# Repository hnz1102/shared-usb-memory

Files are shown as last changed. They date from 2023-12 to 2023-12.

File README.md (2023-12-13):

<div align="center">
  <h1><code>SHARED-USB-MEMORY</code></h1>
  <p>
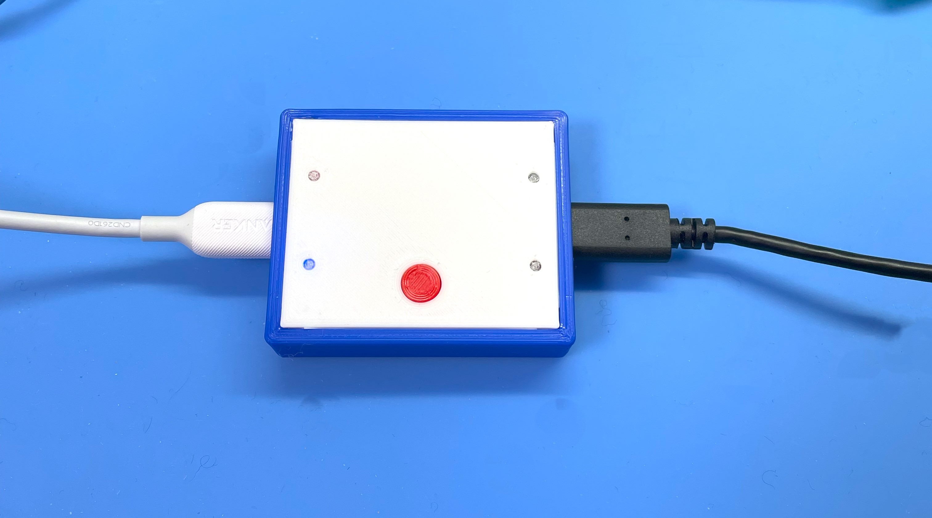
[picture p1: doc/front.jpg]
    
  </p>
</div>

# Shared USB Memory : USB Memory with One-touch Switching Between Two Device Connections

https://github.com/hnz1102/shared-usb-memory/assets/111413646/2c444520-a98f-45e1-a0ac-f0b2667a8621

This memory provides convenient and quick-to-switch connections between two host devices such as PCs.

When the network is not available, data is transferred by copying data to and from a USB memory stick or SD card. However, since removing and inserting USB memory sticks and SD cards is a hassle, the Box can be switched at the touch of a button to pass data back and forth.

To use, connect this Box between two PCs with a Type-C cable. The disk will be recognized by the PC connected to the left port. Then, copy data here, and when the red access blinking stops, press the red button. Then the disk will be recognized in the PC of right port and you can retrieve the data. Press the red button again to return the disk to the left PC. In this way, data can be exchanged without having to remove and insert the USB memory stick.

The box can be run on the Windows OS, MacOS, and Linux OS without special drivers.

## Schematic

This Board Schematic and a PCB layout are placed in this directory. 
Schematic data is created by KidCad 7.0.
The PCB was manufuctured by [PCBWay](https://www.pcbway.com/). I could easily order my custom boards to the PCBWay.
Click online order [page](https://www.pcbway.com/QuickOrderOnline.aspx), then clink the "Add Gerber File" button, you can upload the [gerber file](https://github.com/hnz1102/shared-usb-memory/raw/main/shareusbdisk2.kicad_pcb.zip).

When ordering the PCB, the parameters can be almost default values, but "Min hole size" should be 0.25mm and "Immersion gold (ENIG)" should be selected for "Surface finish". The reason for this is that the minimum Via Hole is 0.25mm, and if the eMMC pad is not "Immersion gold (ENIG)", the solder on the pad will be slightly raised and cannot be soldered properly without misalignment.

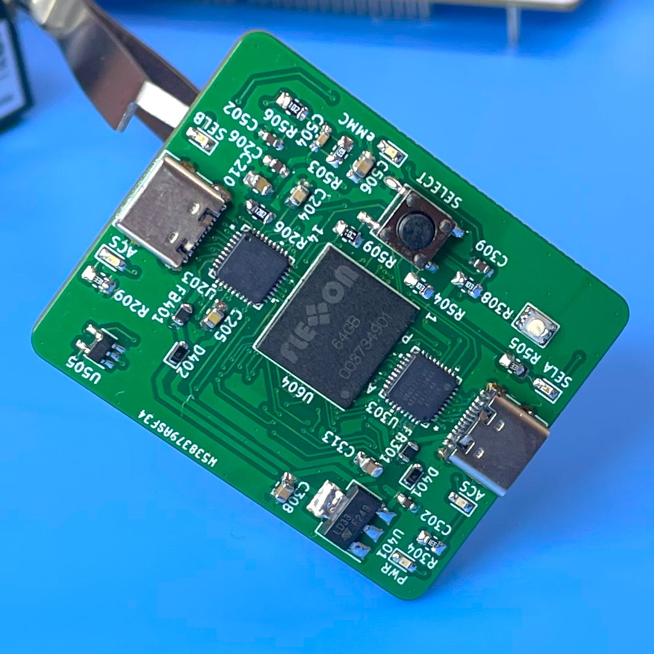
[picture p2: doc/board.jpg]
PCB


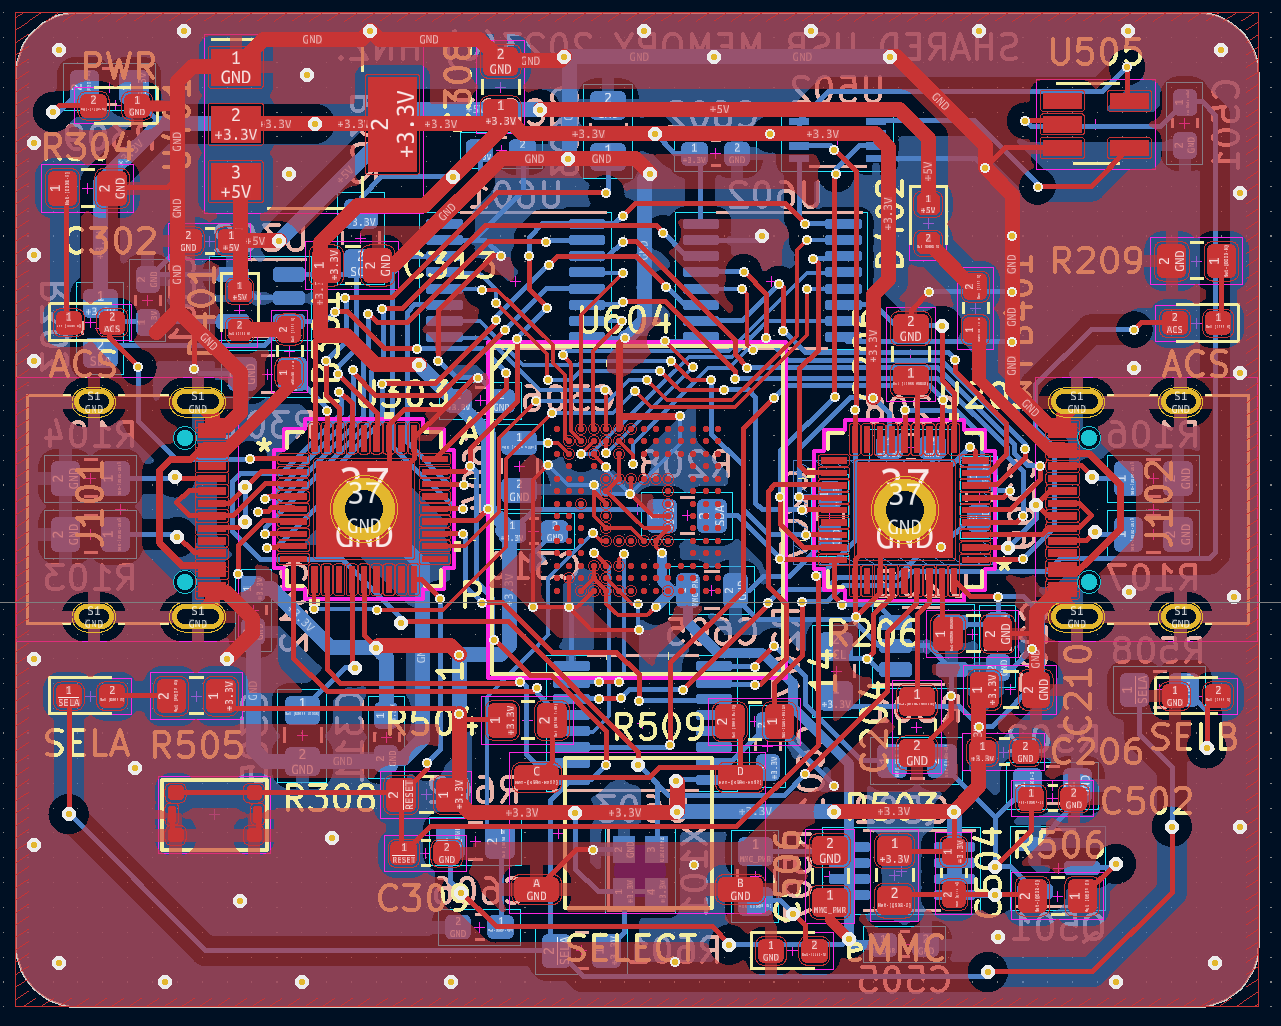
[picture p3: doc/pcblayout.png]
PCB Layout


After assembling the board, It has to configure EEPROMs of the USB Media Controller.

The USB Media Controller has an EEPROM. It is programmed with the parameters by [USBDM tool](https://www.microchip.com/en-us/software-library/usbdm-tool).

- Manufacture String
- Serial Number String

This board has two USB Media Controller. Connect to each of the two respective USB ports and rewrite the information with the USBDM tool. 

# Container

There are STL data for 3D printer in the `stl` directory.

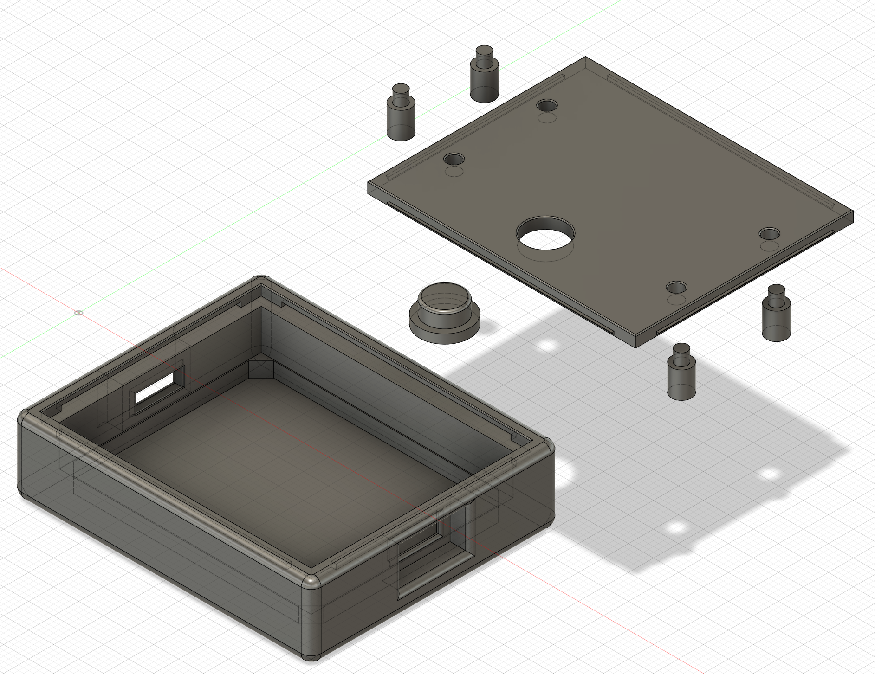
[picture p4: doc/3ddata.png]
container


## LICENSE
Hardware Schematic Documents are licensed under CC-BY-SA V4.0.

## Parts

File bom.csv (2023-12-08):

Reference | Value | Footprint | Datasheet | digikey | storeURL | Qty
C206-C209, C301, C302, C306, C309-C312, C501, C502, C505, C601-C603, C606 | 0.1uF | Capacitor_SMD:C_0603_1608Metric_Pad1.08x0.95mm_HandSolder | ~ | 311-1824-1-ND | https://www.digikey.com/en/products/detail/yageo/CC0603MRX7R7BB104/5195231 | 19
C204, C205, C303, C305 | 1uF | tbctl:C_0805_2012Metric_Pad1.18x1.45mm_HandSolder | ~ | 13-CC0603KPX7R7BB105CT-ND | https://www.digikey.com/en/products/detail/yageo/CC0603KPX7R7BB105/11491211 | 4
C210, C313 | 4.7uF | tbctl:C_0805_2012Metric_Pad1.18x1.45mm_HandSolder | ~ | 311-1455-1-ND | https://www.digikey.com/en/products/detail/yageo/CC0603KRX5R6BB475/2833620 | 2
C308, C506 | 10uF | Capacitor_SMD:C_0805_2012Metric_Pad1.18x1.45mm_HandSolder | ~ | 311-3494-1-ND | https://www.digikey.com/en/products/detail/yageo/CC0603MRX5R8BB106/7164378 | 2
C504 | 2.2uF | Capacitor_SMD:C_0603_1608Metric_Pad1.08x0.95mm_HandSolder | ~ | 311-1795-1-ND | https://www.digikey.com/en/products/detail/yageo/CC0603KRX7R5BB225/5195203 | 1
C604, C605 | 1uF | Capacitor_SMD:C_0805_2012Metric | ~ | 13-CC0603KPX7R7BB105CT-ND | https://www.digikey.com/en/products/detail/yageo/CC0603KPX7R7BB105/11491211 | 2
D203, D301, D302 | LED RED | tbctl:LED_0603_1608Metric_Pad1.05x0.95mm_HandSolder | ~ | 511-1587-1-ND | https://www.digikey.com/en/products/detail/rohm-semiconductor/SML-E12V8WT86/1641806 | 3
D401, D402 | CDBU0520-HF | Diode_SMD:D_0603_1608Metric | https://www.comchiptech.com/admin/files/product/QW-G1012-CDBU40-HF-RevA321692.pdf | 641-2022-1-ND | https://www.digikey.com/en/products/detail/comchip-technology/CDBU0520-HF/3308520 | 2
D501 | eMMC PWR LED RED | tbctl:LED_0603_1608Metric_Pad1.05x0.95mm_HandSolder | ~ | 511-1587-1-ND | https://www.digikey.com/en/products/detail/rohm-semiconductor/SML-E12V8WT86/1641806 | 1
D502 | SEL_A | tbctl:LED_0603_1608Metric_Pad1.05x0.95mm_HandSolder | ~ | 846-1177-1-ND | https://www.digikey.com/en/products/detail/rohm-semiconductor/SMLE13BC8TT86/5053771 | 1
D503 | SEL_B | tbctl:LED_0603_1608Metric_Pad1.05x0.95mm_HandSolder | ~ | 846-1177-1-ND | https://www.digikey.com/en/products/detail/rohm-semiconductor/SMLE13BC8TT86/5053771 | 1
FB301, FB401 | BK2125HS601-T | tbctl:L_0603_1608Metric_Pad1.05x0.95mm_HandSolder | ~ | 240-2399-1-ND | https://www.digikey.com/en/products/detail/laird-signal-integrity-products/HZ0805E601R-10/806759 | 2
J101, J102 | USB_C_Receptacle_USB2.0_5077CR | tbctl:USB_C_5077CR-16-SMC2-BK-TR | https://www.usb.org/sites/default/files/documents/usb_type-c.zip | 2073-USB4105-GF-ACT-ND | https://www.digikey.com/en/products/detail/gct/USB4105-GF-A/11198441 | 2
Q501 | 2N7002K | Package_TO_SOT_SMD:SOT-23 | https://www.diodes.com/assets/Datasheets/ds30896.pdf | 2N7002K-7DICT-ND | https://www.digikey.com/en/products/detail/diodes-incorporated/2N7002K-7/1934378 | 1
Q502 | IRF7606TRPBF | Package_SO:MSOP-8_3x3mm_P0.65mm | http://www.irf.com/product-info/datasheets/data/irf7606pbf.pdf | IRF7606TRPBFCT-ND | https://www.digikey.com/en/products/detail/infineon-technologies/IRF7606TRPBF/856652 | 1
R103, R104, R106, R107 | 5.1K | tbctl:R_0805_2012Metric_Pad1.20x1.40mm_HandSolder | ~ | 13-RC0603JR-1010KLCT-ND | https://www.digikey.com/en/products/detail/yageo/RC0603JR-1010KL/13694233 | 4
R206, R301 | 12K 1% | tbctl:R_0805_2012Metric_Pad1.20x1.40mm_HandSolder | ~ | 311-12.0KHRCT-ND | https://www.digikey.com/en/products/detail/yageo/RC0603FR-0712KL/726913 | 2
R207, R208, R302, R303, R308, R502-R504, R601, R602 | 10K | tbctl:R_0805_2012Metric_Pad1.20x1.40mm_HandSolder | ~ | 13-RC0603JR-1010KLCT-ND | https://www.digikey.com/en/products/detail/yageo/RC0603JR-1010KL/13694233 | 10
R209, R304 | 330R | tbctl:R_0805_2012Metric_Pad1.20x1.40mm_HandSolder | ~ | 311-330GRCT-ND | https://www.digikey.com/en/products/detail/yageo/RC0603JR-07330RL/726769 | 2
R309, R506, R507, R509 | 1K | tbctl:R_0805_2012Metric_Pad1.20x1.40mm_HandSolder | ~ | 13-RC0603JR-101KLCT-ND | https://www.digikey.com/en/products/detail/yageo/RC0603JR-101KL/13694236 | 4
R501 | 2K | tbctl:R_0805_2012Metric_Pad1.20x1.40mm_HandSolder | ~ | 311-2.0KGRCT-ND | https://www.digikey.com/en/products/detail/yageo/RC0603JR-072KL/726726 | 1
R505, R508 | 330 | tbctl:R_0805_2012Metric_Pad1.20x1.40mm_HandSolder | ~ | 13-RC0603JR-101KLCT-ND | https://www.digikey.com/en/products/detail/yageo/RC0603JR-101KL/13694236 | 2
SW301 | RESET SW | tbctl:WS-TASV SMT Tact Switch |  | 732-435151014824CT-ND | https://www.digikey.com/en/products/detail/w%C3%BCrth-elektronik/435151014824/11627325 | 1
SW501 | TS-06104 | tbctl:TS-06104 |  |  | https://akizukidenshi.com/catalog/g/gP-15969/ | 1
U202, U302 | AT24C04-STUM | Package_TO_SOT_SMD:SOT-23-5 | http://ww1.microchip.com/downloads/en/DeviceDoc/Atmel-8766-SEEPROM-AT24CS04-08-Datasheet.pdf | AT24C04C-STUM-TCT-ND | https://www.digikey.com/en/products/detail/microchip-technology/AT24C04C-STUM-T/3789511 | 2
U203, U303 | USB2244-AEZG-06 | tbctl:QFN36_6X6MC_MCH | USB2244-AEZG-06 | USB2244-AEZG-06-ND | https://www.digikey.com/en/products/detail/microchip-technology/USB2244-AEZG-06/3873146 | 2
U401 | LD1117S33TR_SOT223 | Package_TO_SOT_SMD:SOT-223-3_TabPin2 | http://www.st.com/st-web-ui/static/active/en/resource/technical/document/datasheet/CD00000544.pdf | 497-1242-1-ND | https://www.digikey.com/en/products/detail/stmicroelectronics/LD1117S33TR/585766 | 1
U502 | 74LVC2G74 | Package_SO:VSSOP-8_2.3x2mm_P0.5mm |  | TC7W74FKLFCT-ND | https://www.digikey.com/en/products/detail/toshiba-semiconductor-and-storage/TC7W74FK-LF/870742 | 1
U505 | 74AHC1G14 | Package_TO_SOT_SMD:SOT-23-5_HandSoldering |  | 74AHC1G14W5-7DICT-ND | https://www.digikey.com/en/products/detail/diodes-incorporated/74AHC1G14W5-7/2639249 | 1
U601-U603 | TMUX1574PWR | Package_SO:TSSOP-16_4.4x5mm_P0.65mm |  | 296-53444-1-ND | https://www.digikey.com/en/products/detail/texas-instruments/TMUX1574PWR/9954224 | 3
U604 | EM32VSUKN | tbctl:EM32VSUKN FPGA153 |  | 3247-EM32VSUKN-BA000-2-ND | https://www.digikey.com/en/products/detail/delkin-devices-inc/EM32VSUKN-BA000-2/16357650 | 1
X101 | SG-210STF 24MHz | Oscillator:Oscillator_SMD_SeikoEpson_SG210-4Pin_2.5x2.0mm | https://support.epson.biz/td/api/doc_check.php?mode=dl&lang=en&Parts=SG-210STF | SER4078CT-ND | https://www.digikey.com/en/products/detail/epson/SG-210STF-24-0000ML0/4437389 | 1

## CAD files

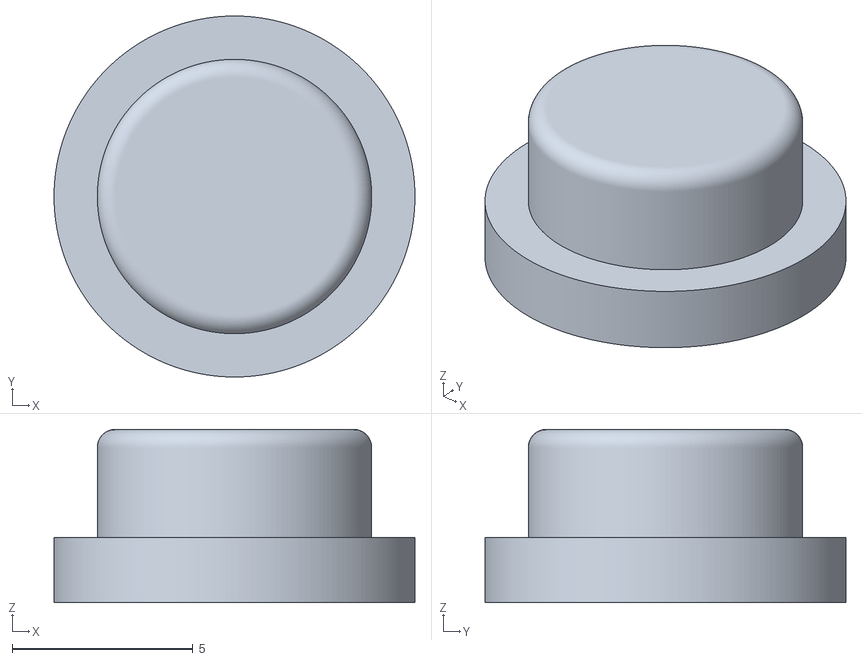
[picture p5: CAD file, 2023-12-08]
stl/button-v6.stl
10.0 x 10.00 x 4.80

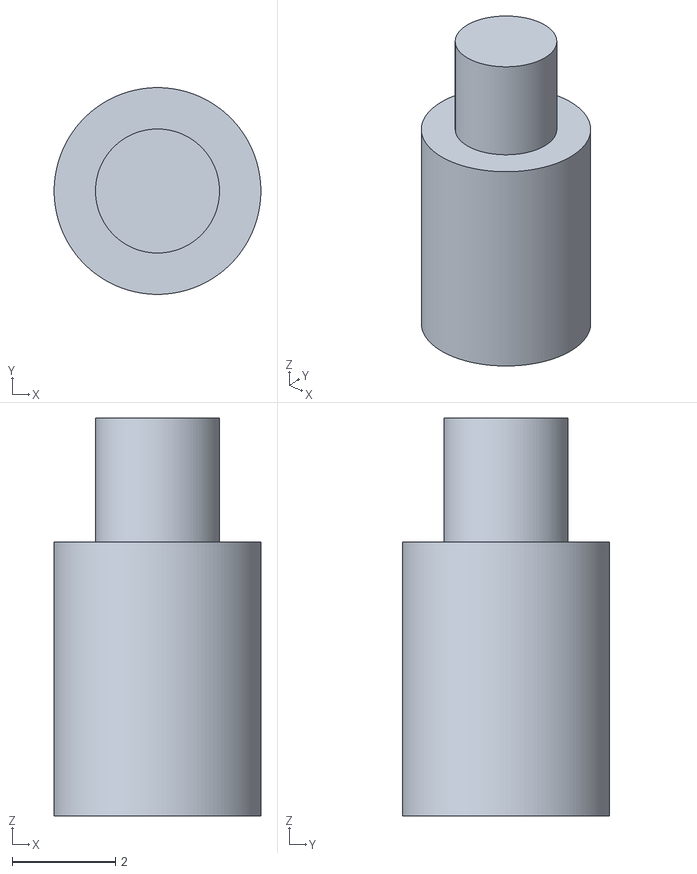
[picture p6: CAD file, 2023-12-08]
stl/LED3-v10.stl
4.00 x 4.00 x 7.70

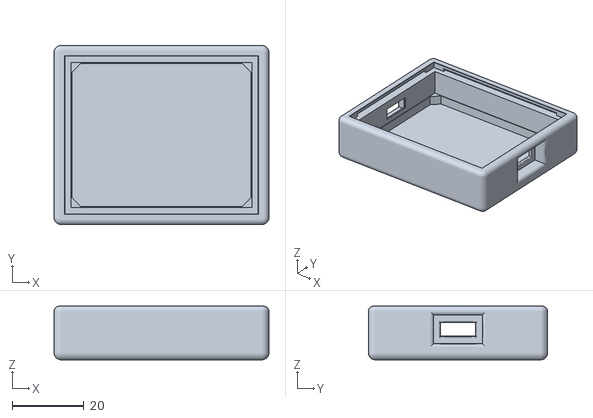
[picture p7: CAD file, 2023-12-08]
stl/bottom-v7.stl
60.0 x 50.0 x 15.0

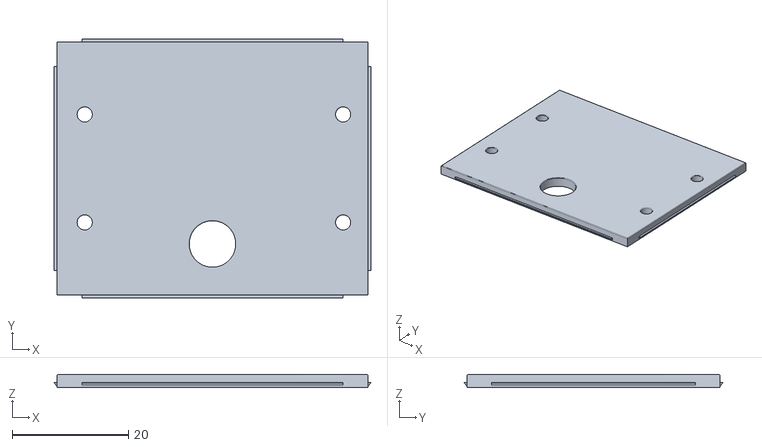
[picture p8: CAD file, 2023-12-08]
stl/upper-v11.stl
54.6 x 44.6 x 2.20

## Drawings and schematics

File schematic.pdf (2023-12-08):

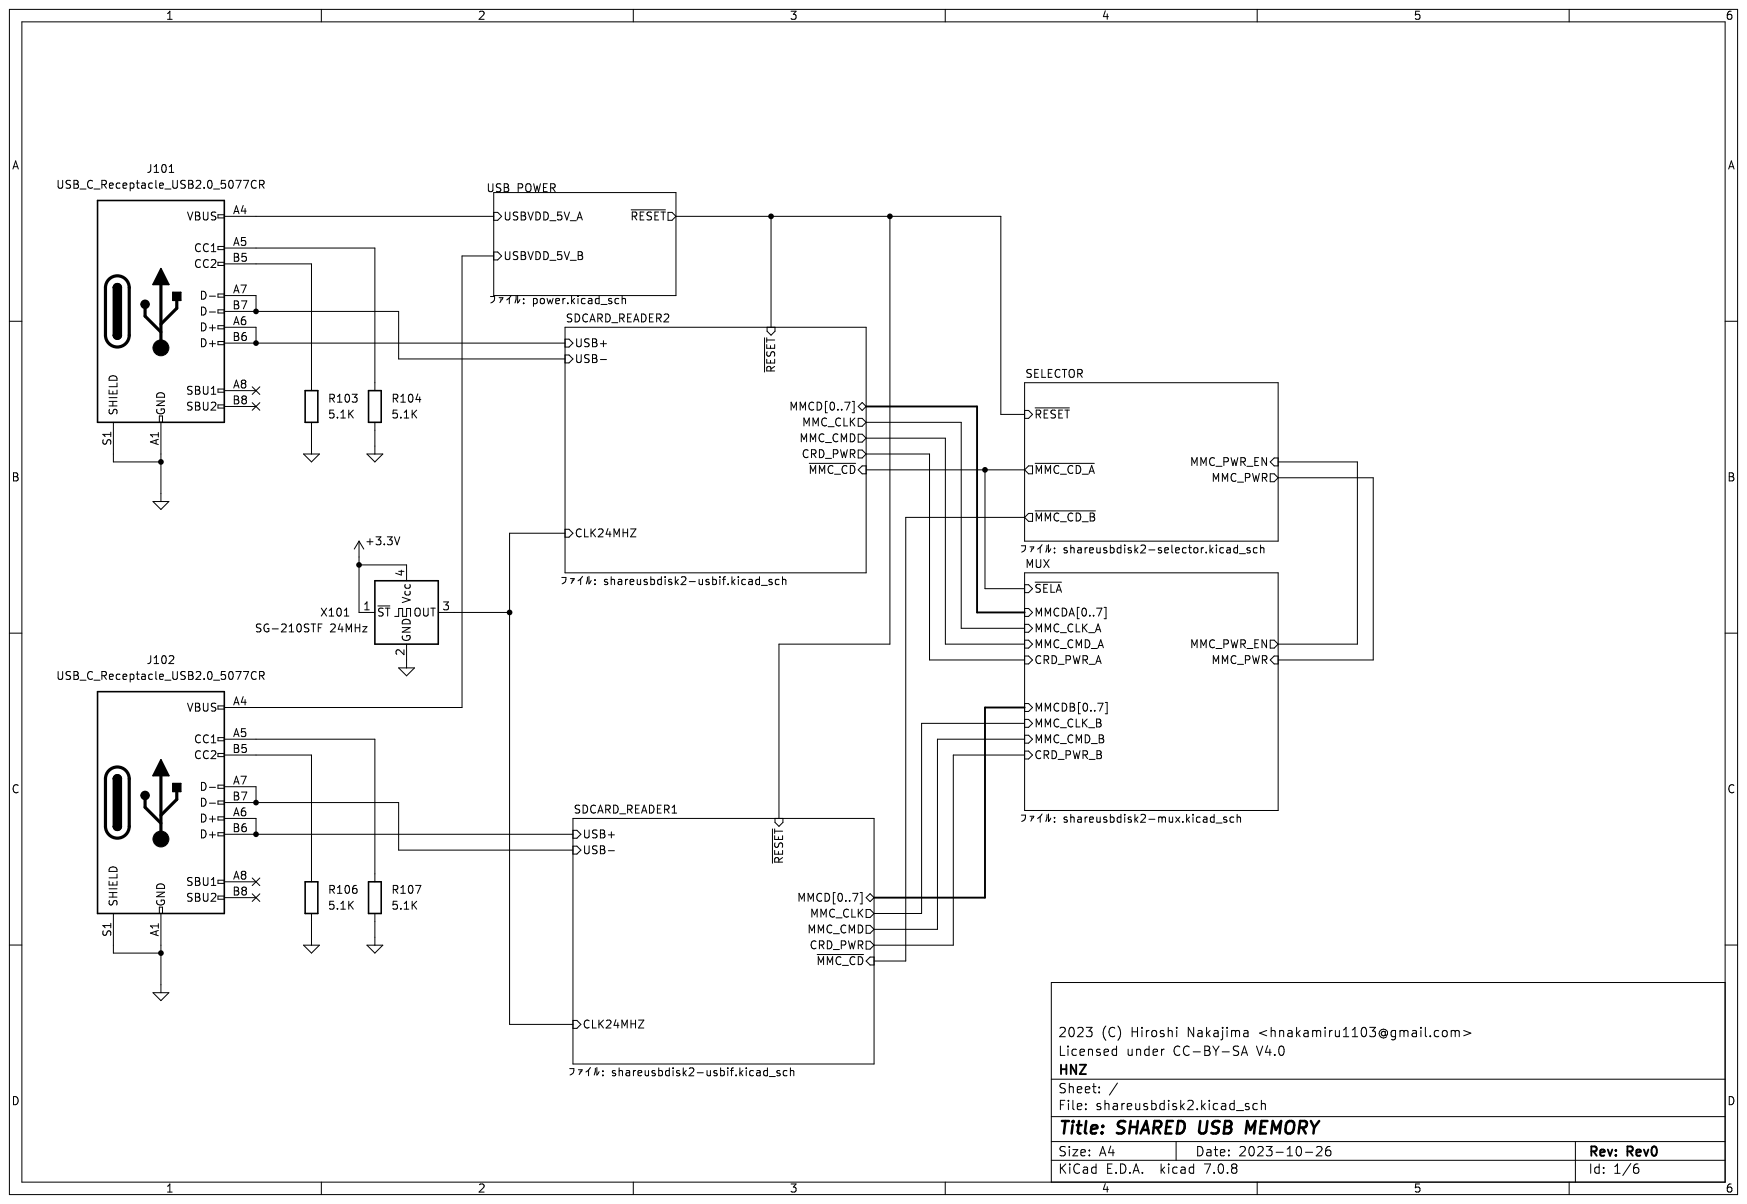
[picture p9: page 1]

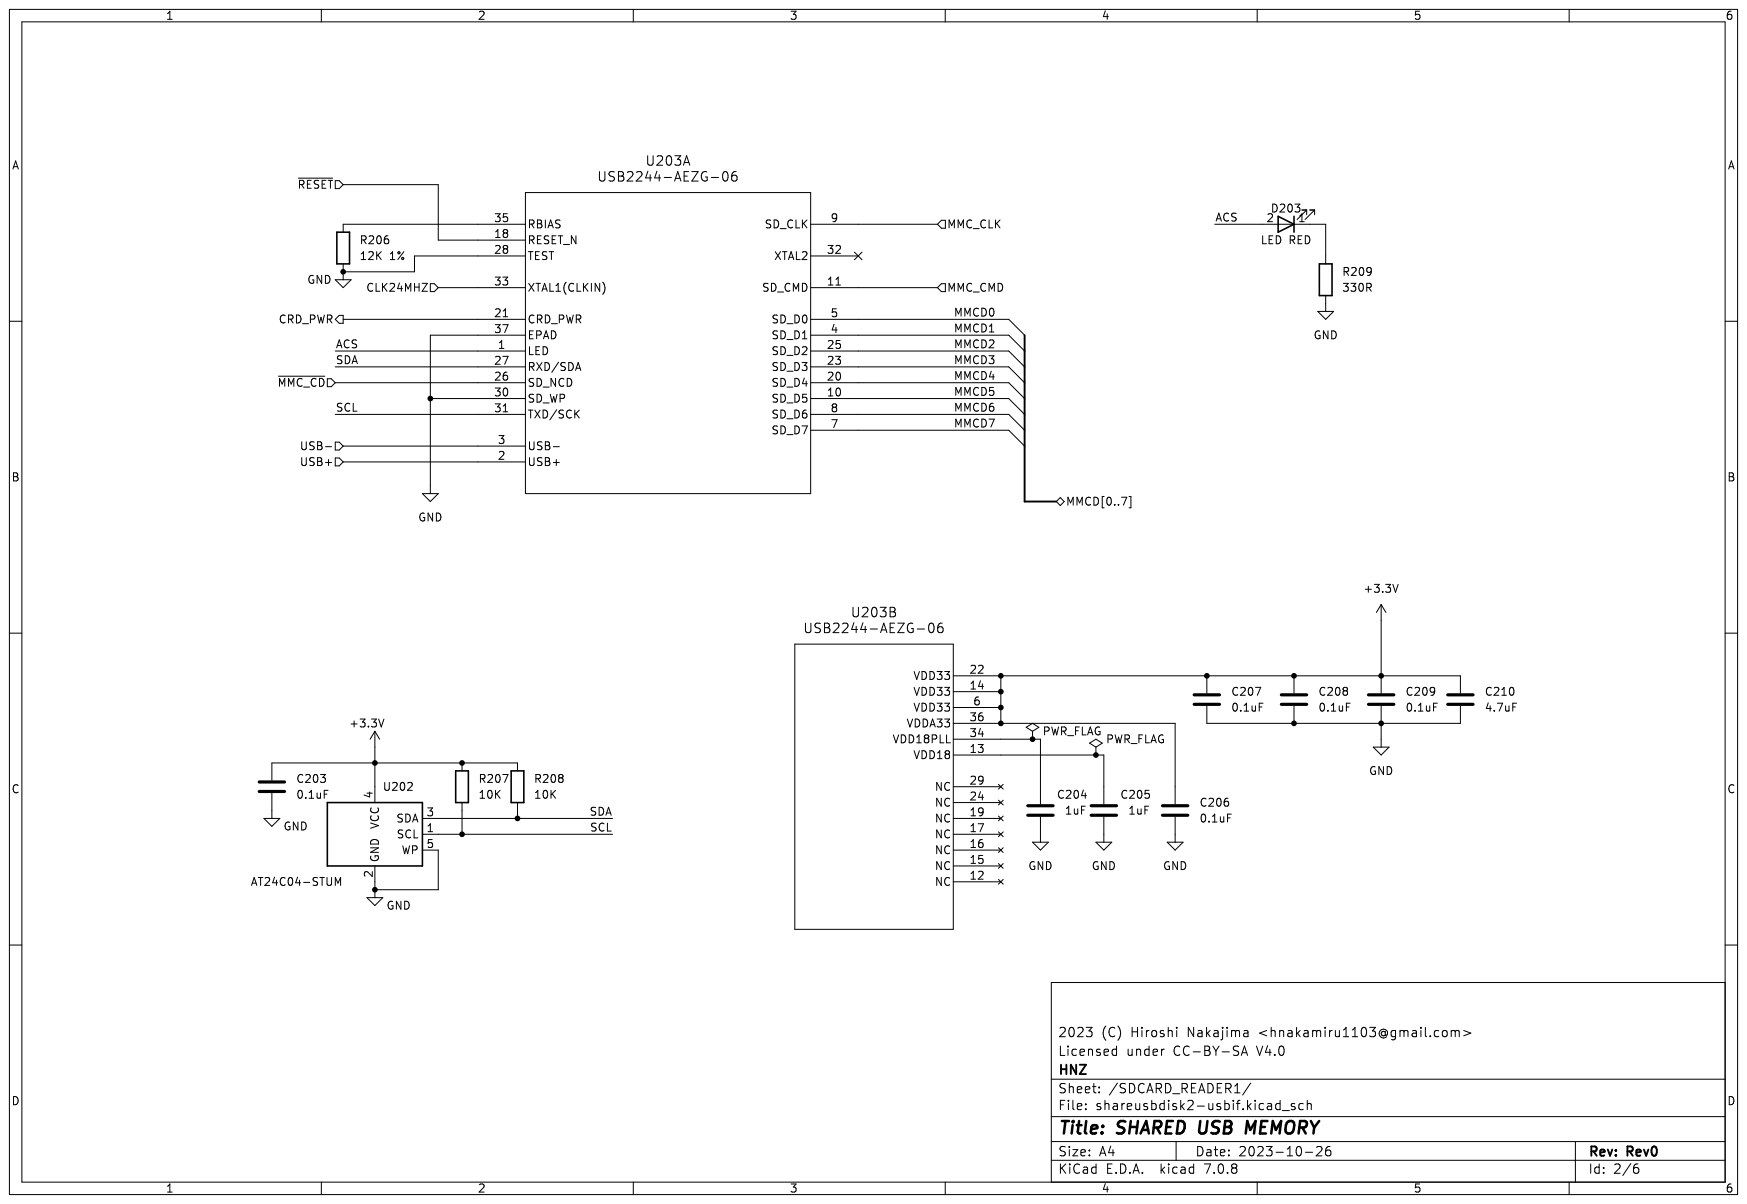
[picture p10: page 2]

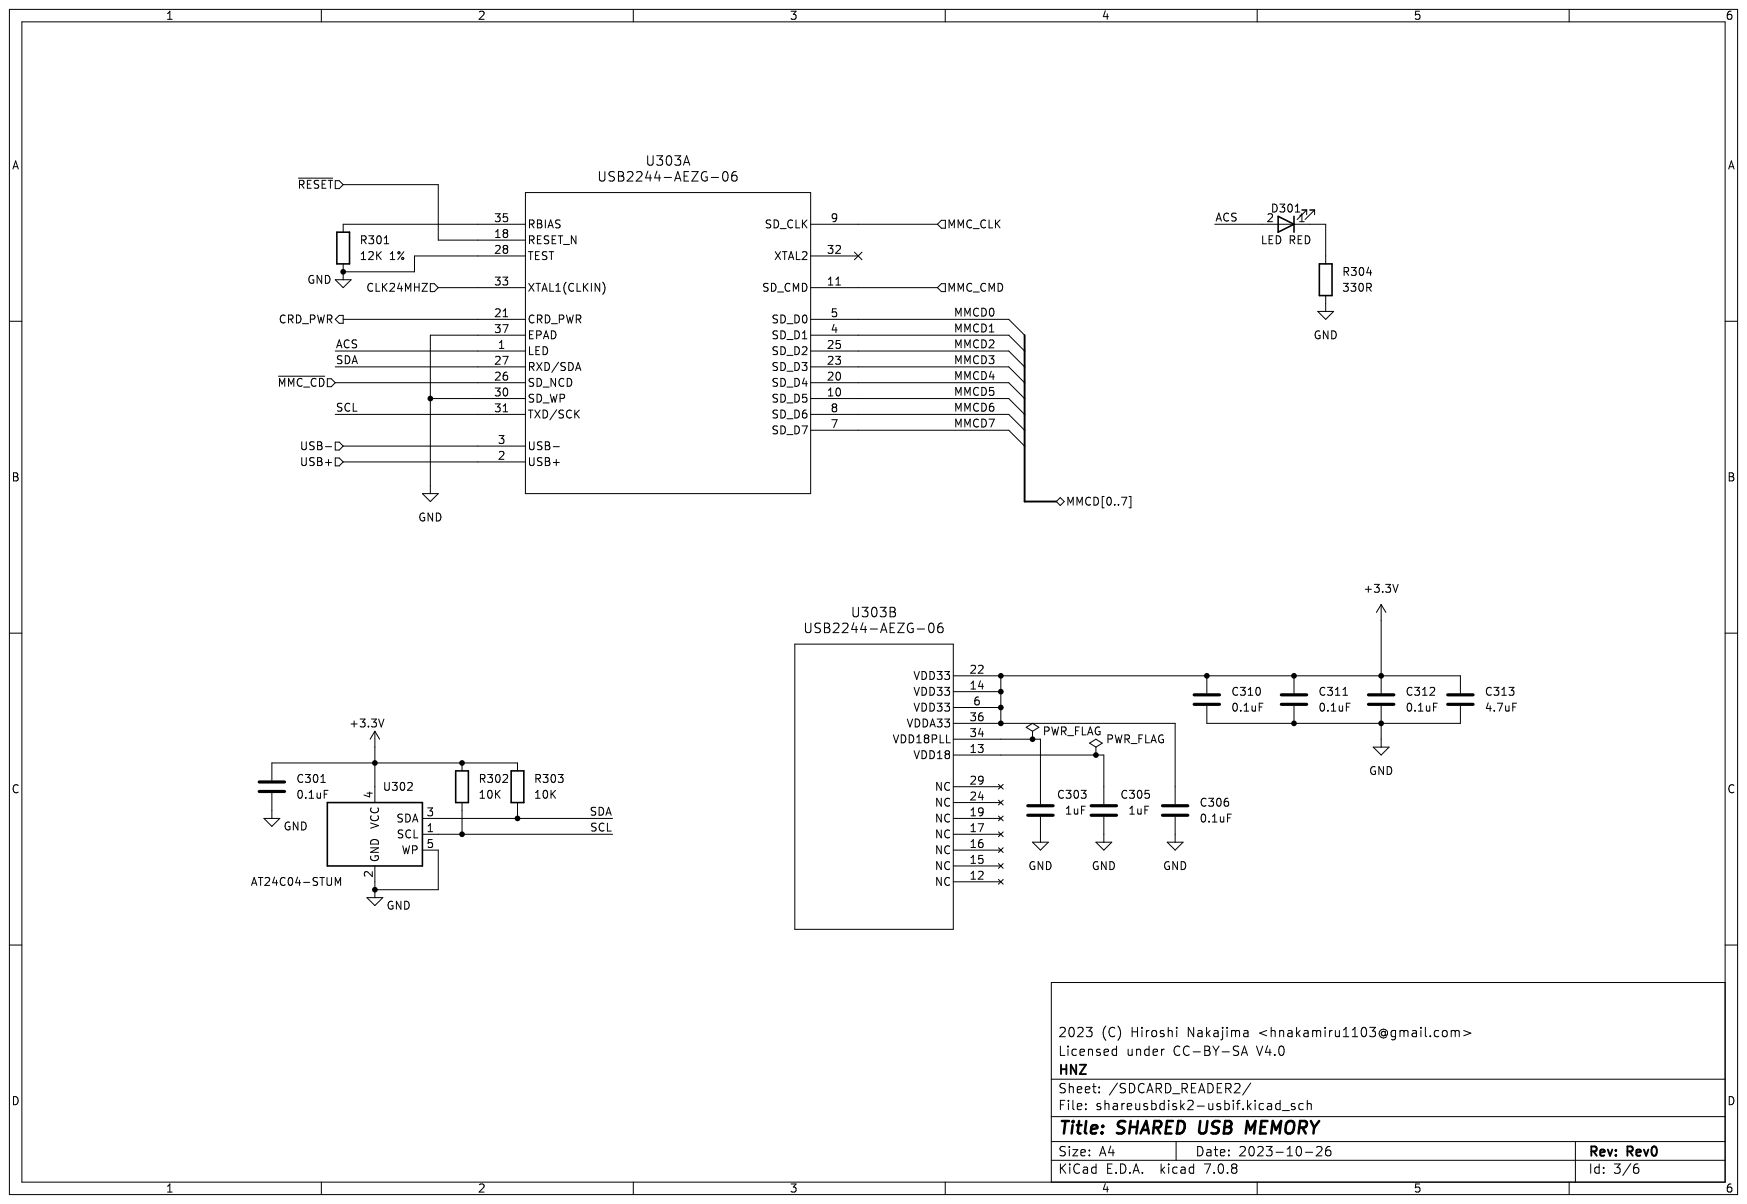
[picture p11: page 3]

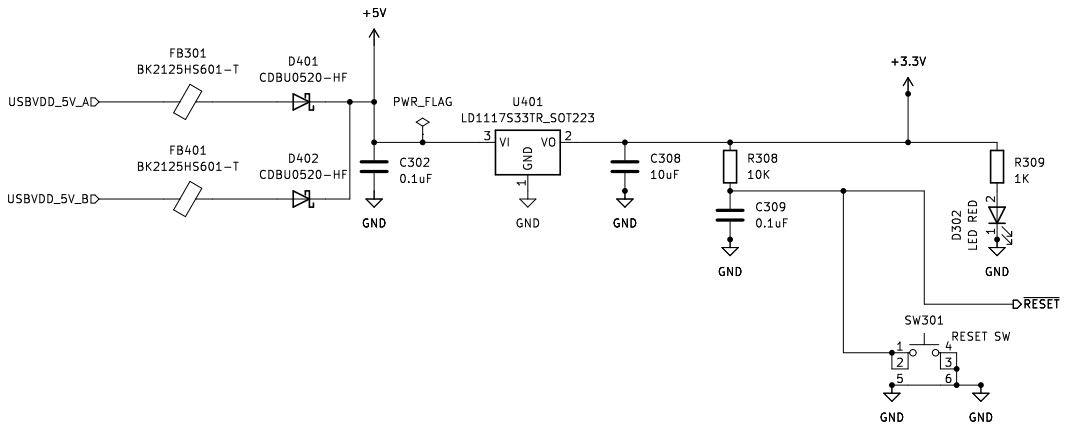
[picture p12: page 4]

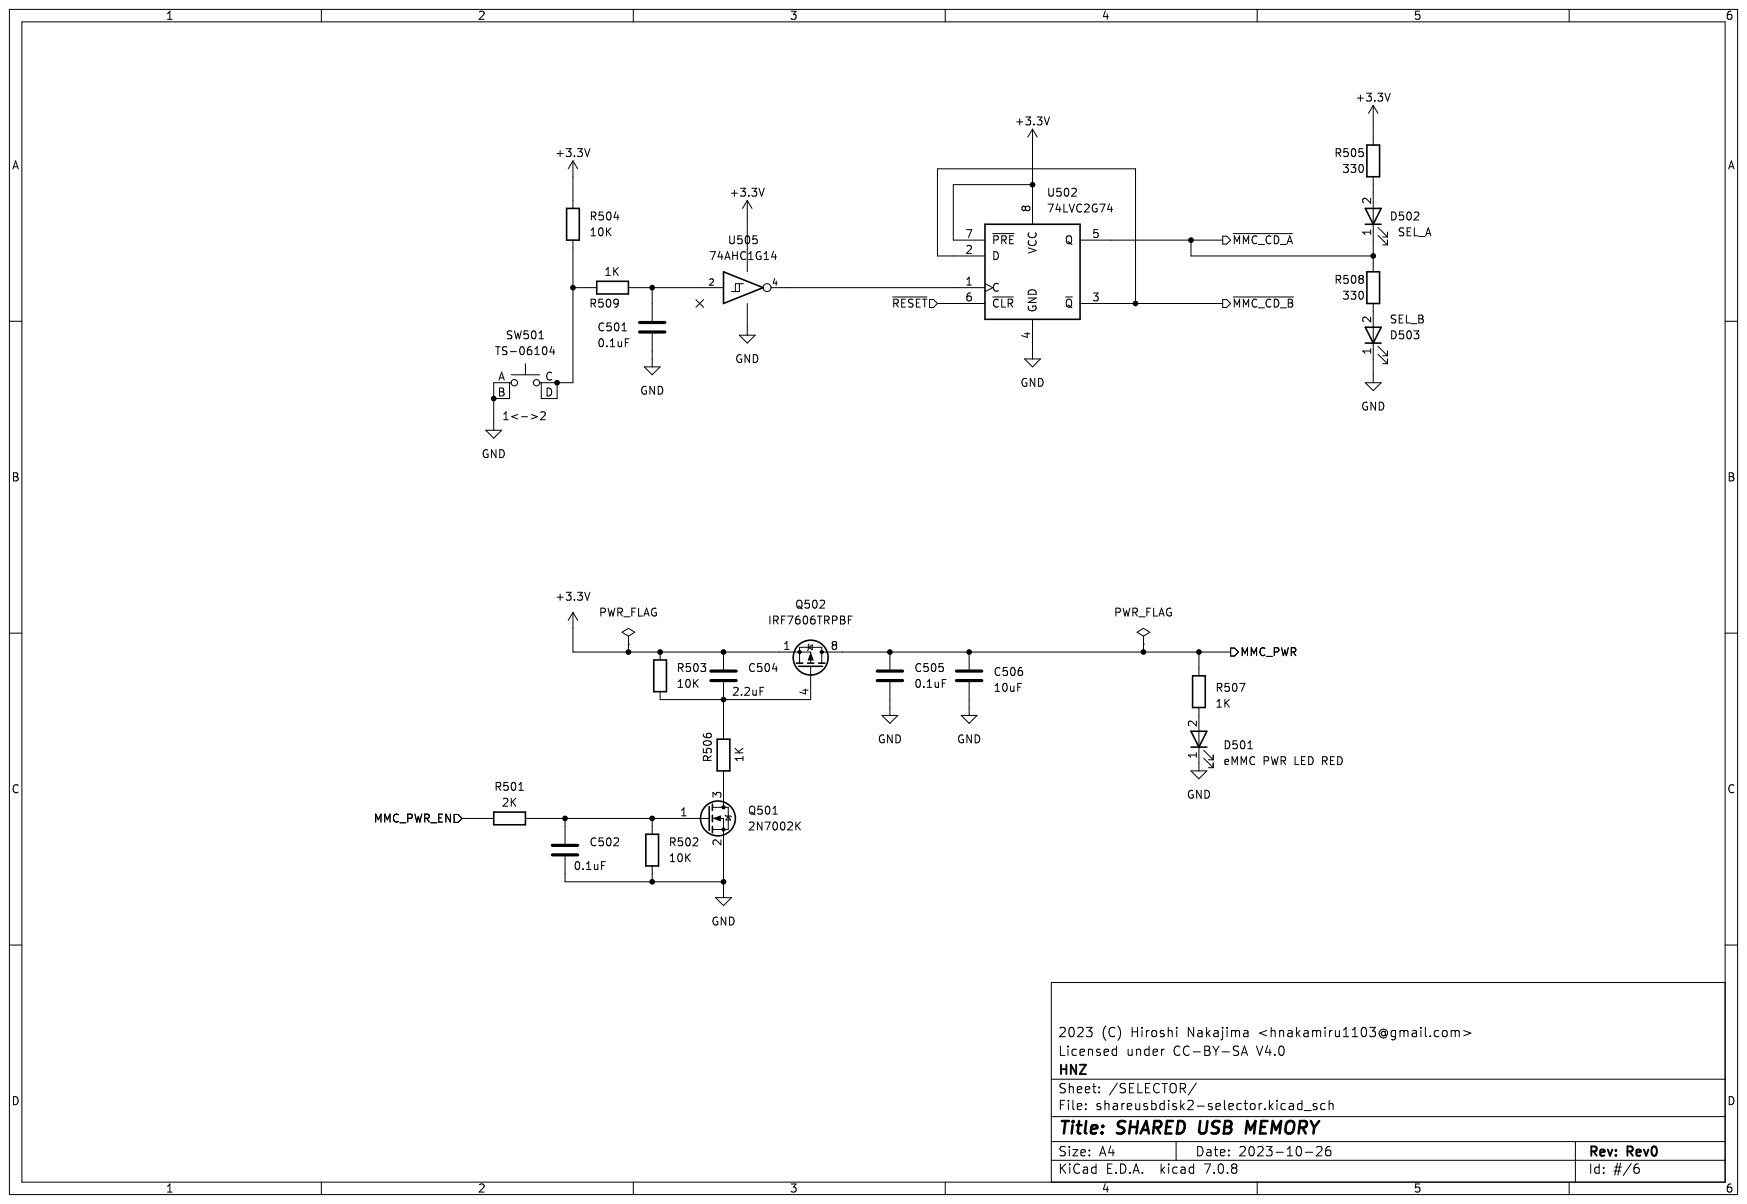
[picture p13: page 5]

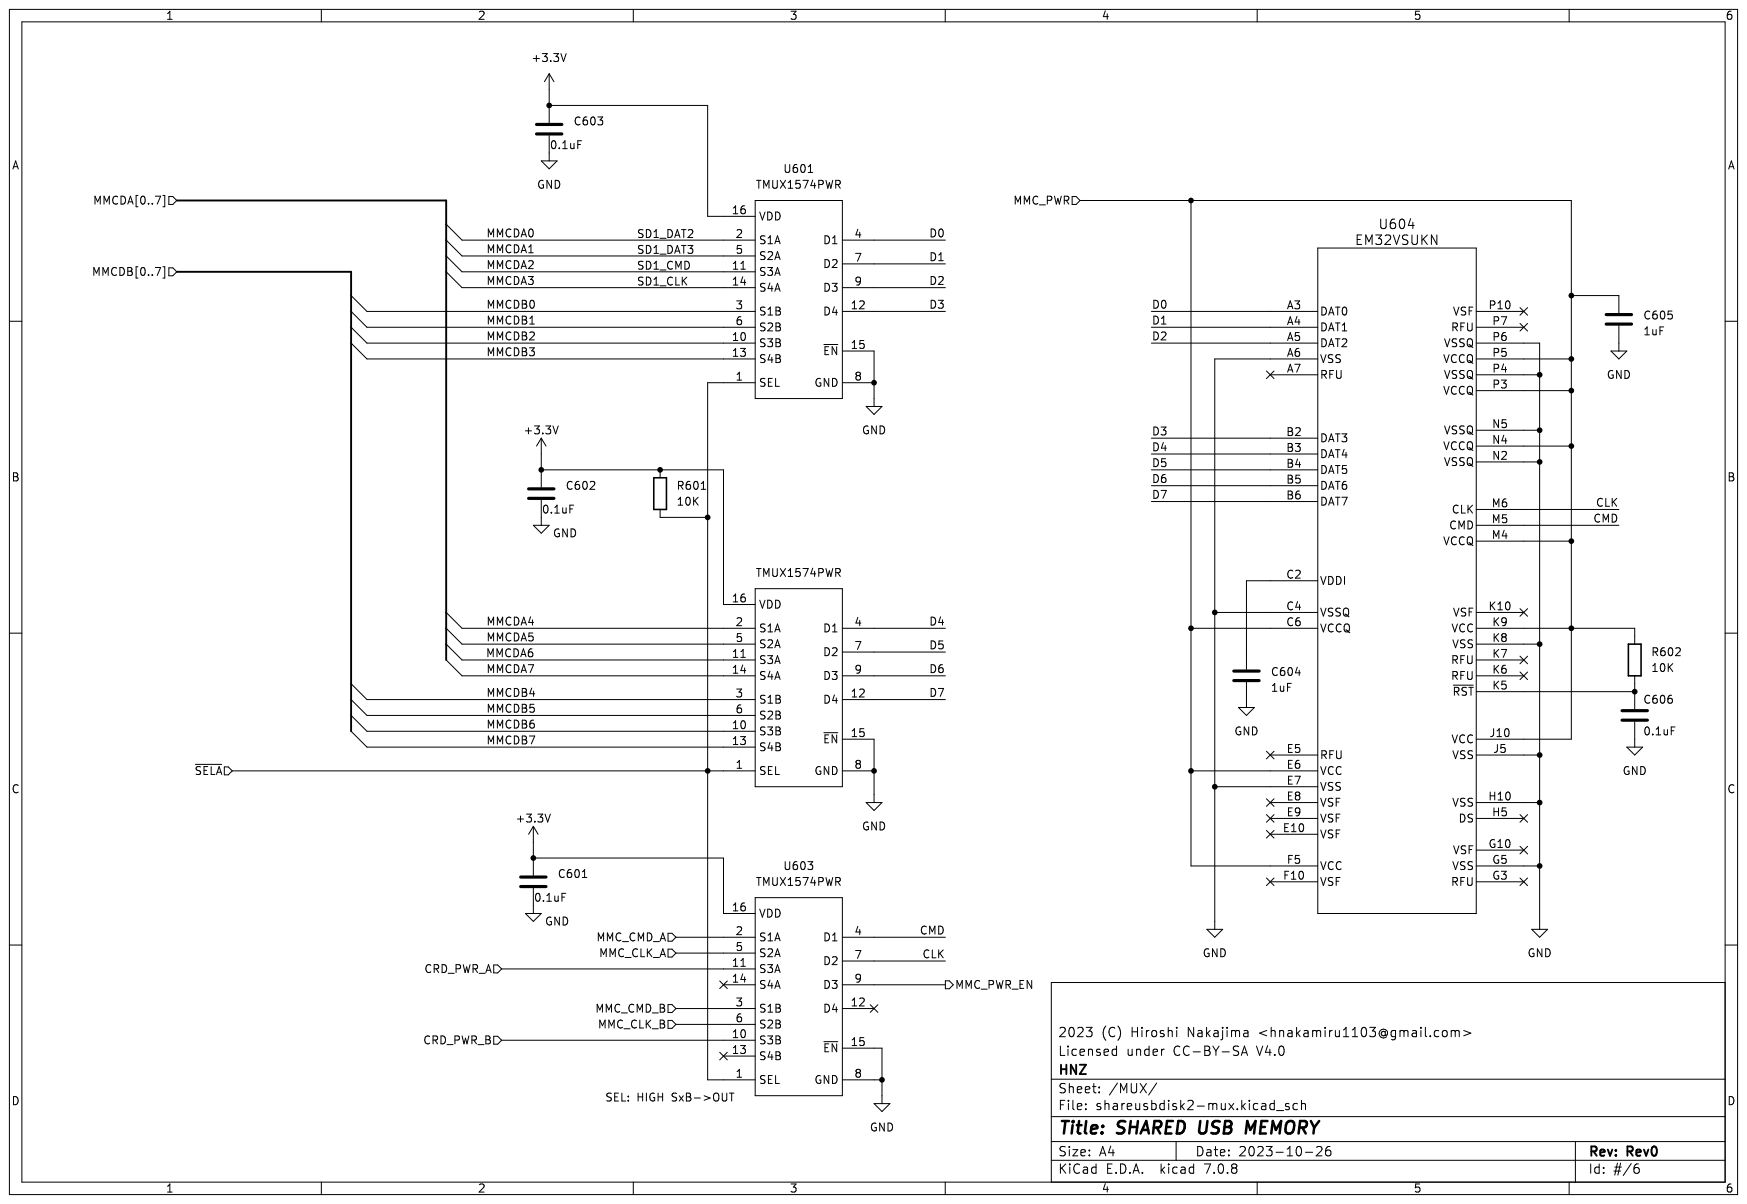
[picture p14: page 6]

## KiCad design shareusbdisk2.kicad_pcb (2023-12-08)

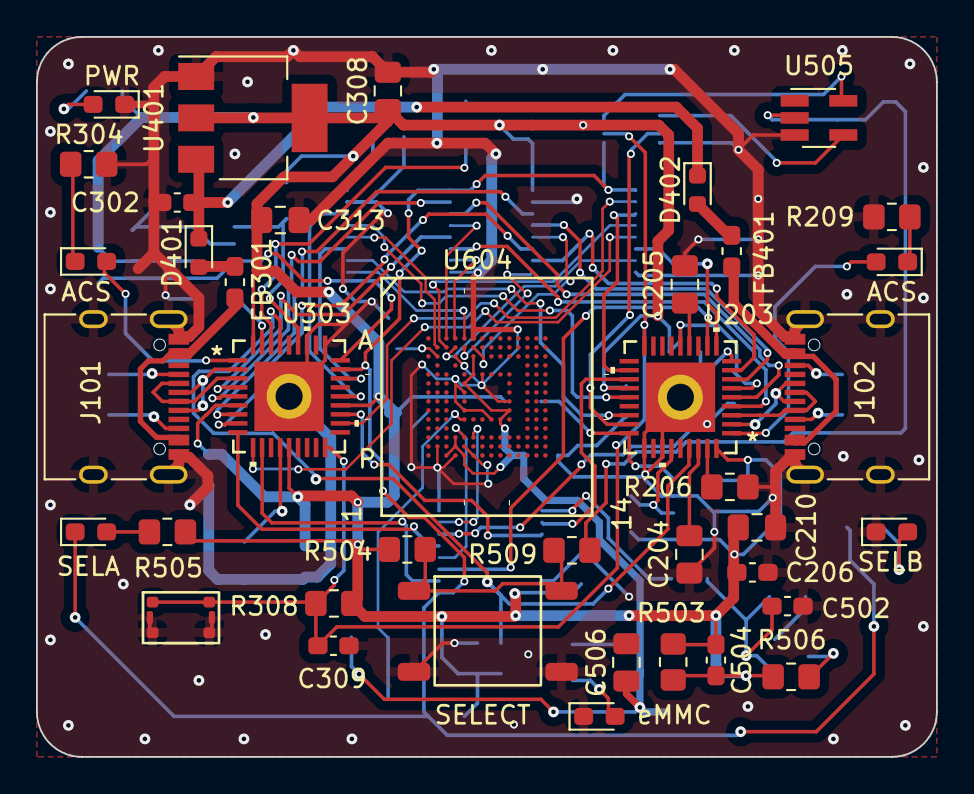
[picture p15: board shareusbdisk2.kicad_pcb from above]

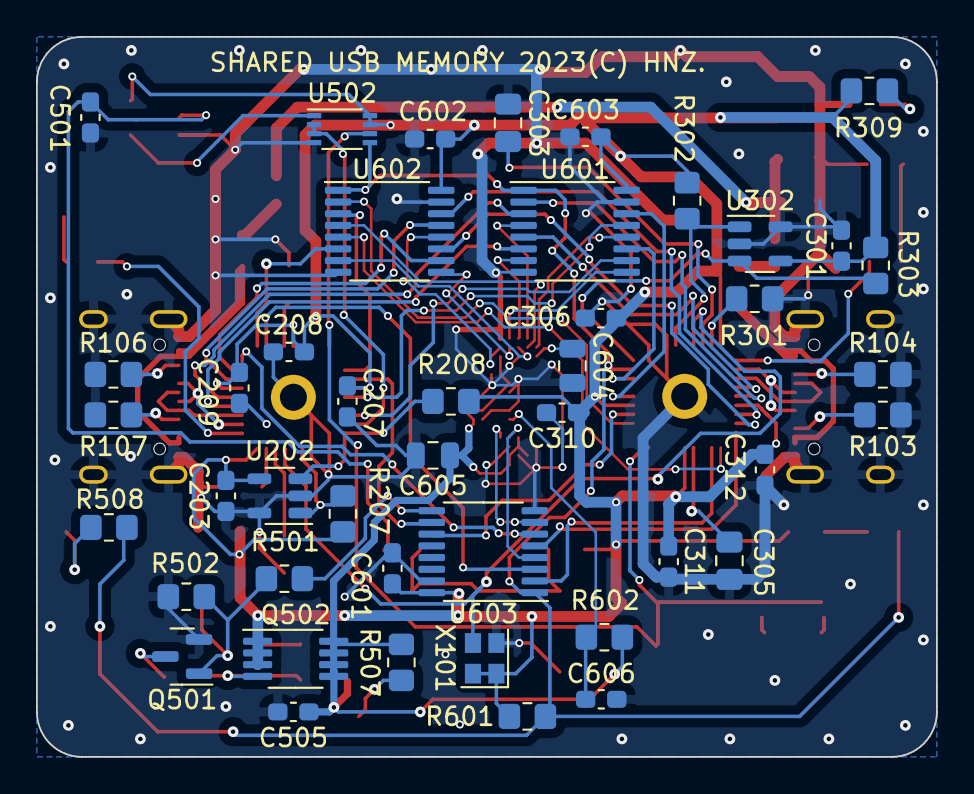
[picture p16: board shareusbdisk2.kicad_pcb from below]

Board: 2 copper layers, 50.0 x 40.0 mm, 83 parts (44 on the bottom side), 79 nets.

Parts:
C203, C206, C207, C208, C209, C301, C302, C306, C309, C310, C311, C312, C501, C502, C505, C601, C602, C603, C606: 0.1uF; C_0603_1608Metric_Pad1.08x0.95mm_HandSolder
C204, C205, C303, C305: 1uF; C_0805_2012Metric_Pad1.18x1.45mm_HandSolder
C210, C313: 4.7uF; C_0805_2012Metric_Pad1.18x1.45mm_HandSolder
C308, C506: 10uF; C_0805_2012Metric_Pad1.18x1.45mm_HandSolder
C504: 2.2uF; C_0603_1608Metric_Pad1.08x0.95mm_HandSolder
C604, C605: 1uF; C_0805_2012Metric
D203, D301, D302: LED RED; LED_0603_1608Metric_Pad1.05x0.95mm_HandSolder
D401, D402: CDBU0520-HF; D_0603_1608Metric
D501: eMMC PWR LED RED; LED_0603_1608Metric_Pad1.05x0.95mm_HandSolder
D502: SEL_A; LED_0603_1608Metric_Pad1.05x0.95mm_HandSolder
D503: SEL_B; LED_0603_1608Metric_Pad1.05x0.95mm_HandSolder
FB301, FB401: BK2125HS601-T; L_0603_1608Metric_Pad1.05x0.95mm_HandSolder
J101, J102: USB_C_Receptacle_USB2.0_5077CR; USB_C_5077CR-16-SMC2-BK-TR
Q501: 2N7002K; SOT-23
Q502: IRF7606TRPBF; MSOP-8_3x3mm_P0.65mm
R103, R104, R106, R107: 5.1K; R_0805_2012Metric_Pad1.20x1.40mm_HandSolder
R206, R301: 12K 1%; R_0805_2012Metric_Pad1.20x1.40mm_HandSolder
R207, R208, R302, R303, R308, R502, R503, R504, R601, R602: 10K; R_0805_2012Metric_Pad1.20x1.40mm_HandSolder
R209, R304: 330R; R_0805_2012Metric_Pad1.20x1.40mm_HandSolder
R309, R506, R507, R509: 1K; R_0805_2012Metric_Pad1.20x1.40mm_HandSolder
R501: 2K; R_0805_2012Metric_Pad1.20x1.40mm_HandSolder
R505, R508: 330; R_0805_2012Metric_Pad1.20x1.40mm_HandSolder
SW301: RESET SW; WS-TASV SMT Tact Switch
SW501: TS-06104
U202, U302: AT24C04-STUM; SOT-23-5
U203, U303: USB2244-AEZG-06; QFN36_6X6MC_MCH
U401: LD1117S33TR_SOT223; SOT-223-3_TabPin2
U502: 74LVC2G74; VSSOP-8_2.3x2mm_P0.5mm
U505: 74AHC1G14; SOT-23-5_HandSoldering
U601, U602, U603: TMUX1574PWR; TSSOP-16_4.4x5mm_P0.65mm
U604: EM32VSUKN; EM32VSUKN FPGA153
X101: SG-210STF 24MHz; Oscillator_SMD_SeikoEpson_SG210-4Pin_2.5x2.0mm

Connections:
+3.3V: C203.1, C206.1, C207.1, C208.1, C209.1, C210.1, C301.1, C306.1, C308.1, C310.1, C311.1, C312.1, C313.1, C504.1, C601.1, C602.1, C603.1, Q502.1 (S), Q502.2 (S), Q502.3 (S), R207.1, R208.1, R302.1, R303.1, R308.1, R309.1, R503.1, R504.1, R505.1, R601.1, U202.4 (VCC), U203.6 (VDD33), U203.14 (VDD33), U203.22 (VDD33), U203.36 (VDDA33), U302.4 (VCC), U303.6 (VDD33), U303.14 (VDD33), U303.22 (VDD33), U303.36 (VDDA33), U401.2 (VO), U502.7 (~PRE), U502.8 (VCC), U505.5 (VCC), U601.16 (VDD), U602.16 (VDD), U603.16 (VDD), X101.1 (~ST), X101.4 (Vcc)
+5V: C302.1, D401.1 (K), D402.1 (K), U401.3 (VI)
/MUX/CLK: U603.7 (D2), U604.M6 (CLK)
/MUX/CMD: U603.4 (D1), U604.M5 (CMD)
/MUX/CRD_PWR_A: U303.21 (CRD_PWR), U603.11 (S3A)
/MUX/CRD_PWR_B: U203.21 (CRD_PWR), U603.10 (S3B)
/MUX/D0: U601.4 (D1), U604.A3 (DAT0)
/MUX/D1: U601.7 (D2), U604.A4 (DAT1)
/MUX/D2: U601.9 (D3), U604.A5 (DAT2)
/MUX/D3: U601.12 (D4), U604.B2 (DAT3)
/MUX/D4: U602.4 (D1), U604.B3 (DAT4)
/MUX/D5: U602.7 (D2), U604.B4 (DAT5)
/MUX/D6: U602.9 (D3), U604.B5 (DAT6)
/MUX/D7: U602.12 (D4), U604.B6 (DAT7)
/MUX/MMCDA0: U303.5 (SD_D0), U601.2 (S1A)
/MUX/MMCDA1: U303.4 (SD_D1), U601.5 (S2A)
/MUX/MMCDA2: U303.25 (SD_D2), U601.11 (S3A)
/MUX/MMCDA3: U303.23 (SD_D3), U601.14 (S4A)
/MUX/MMCDA4: U303.20 (SD_D4), U602.2 (S1A)
/MUX/MMCDA5: U303.10 (SD_D5), U602.5 (S2A)
/MUX/MMCDA6: U303.8 (SD_D6), U602.11 (S3A)
/MUX/MMCDA7: U303.7 (SD_D7), U602.14 (S4A)
/MUX/MMCDB0: U203.5 (SD_D0), U601.3 (S1B)
/MUX/MMCDB1: U203.4 (SD_D1), U601.6 (S2B)
/MUX/MMCDB2: U203.25 (SD_D2), U601.10 (S3B)
/MUX/MMCDB3: U203.23 (SD_D3), U601.13 (S4B)
/MUX/MMCDB4: U203.20 (SD_D4), U602.3 (S1B)
/MUX/MMCDB5: U203.10 (SD_D5), U602.6 (S2B)
/MUX/MMCDB6: U203.8 (SD_D6), U602.10 (S3B)
/MUX/MMCDB7: U203.7 (SD_D7), U602.13 (S4B)
/MUX/MMC_CLK_A: U303.9 (SD_CLK), U603.5 (S2A)
/MUX/MMC_CLK_B: U203.9 (SD_CLK), U603.6 (S2B)
/MUX/MMC_CMD_A: U303.11 (SD_CMD), U603.2 (S1A)
/MUX/MMC_CMD_B: U203.11 (SD_CMD), U603.3 (S1B)
/MUX/MMC_PWR: C505.1, C506.1, C605.1, Q502.5 (D), Q502.6 (D), Q502.7 (D), Q502.8 (D), R507.1, R602.1, U604.C6 (VCCQ), U604.E6 (VCC), U604.F5 (VCC), U604.J10 (VCC), U604.K9 (VCC), U604.M4 (VCCQ), U604.N4 (VCCQ), U604.P3 (VCCQ), U604.P5 (VCCQ)
/MUX/MMC_PWR_EN: R501.1, U603.9 (D3)
/MUX/~SELA: D502.1 (K), R508.1, R601.2, U303.26 (SD_NCD), U502.5 (Q), U601.1 (SEL), U602.1 (SEL), U603.1 (SEL)
/SDCARD_READER1/ACS: D203.2 (A), U203.1 (LED)
/SDCARD_READER1/CLK24MHZ: U203.33 (XTAL1(CLKIN)), U303.33 (XTAL1(CLKIN)), X101.3 (OUT)
/SDCARD_READER1/SCL: R207.2, U202.1 (SCL), U203.31 (TXD/SCK)
/SDCARD_READER1/SDA: R208.2, U202.3 (SDA), U203.27 (RXD/SDA)
/SDCARD_READER1/USB+: J102.A6 (D+), J102.B6 (D+), U203.2 (USB+)
/SDCARD_READER1/USB-: J102.A7 (D-), J102.B7 (D-), U203.3 (USB-)
/SDCARD_READER1/~MMC_CD: U203.26 (SD_NCD), U502.2 (D), U502.3 (~Q)
/SDCARD_READER1/~RESET: C309.1, R308.2, SW301.1, SW301.2, U203.18 (RESET_N), U303.18 (RESET_N), U502.6 (~CLR)
/SDCARD_READER2/ACS: D301.2 (A), U303.1 (LED)
/SDCARD_READER2/SCL: R302.2, U302.1 (SCL), U303.31 (TXD/SCK)
/SDCARD_READER2/SDA: R303.2, U302.3 (SDA), U303.27 (RXD/SDA)
/SDCARD_READER2/USB+: J101.A6 (D+), J101.B6 (D+), U303.2 (USB+)
/SDCARD_READER2/USB-: J101.A7 (D-), J101.B7 (D-), U303.3 (USB-)
/USB POWER/USBVDD_5V_A: FB301.1, J101.A4 (VBUS), J101.A9 (VBUS), J101.B4 (VBUS), J101.B9 (VBUS)
/USB POWER/USBVDD_5V_B: FB401.1, J102.A4 (VBUS), J102.A9 (VBUS), J102.B4 (VBUS), J102.B9 (VBUS)
GND: C203.2, C204.2, C205.2, C206.2, C207.2, C208.2, C209.2, C210.2, C301.2, C302.2, C303.2, C305.2, C306.2, C308.2, C309.2, C310.2, C311.2, C312.2, C313.2, C501.2, C502.2, C505.2, C506.2, C601.2, C602.2, C603.2, C604.2, C605.2, C606.2, D302.1 (K), D501.1 (K), D503.1 (K), J101.A1 (GND), J101.A12 (GND), J101.B1 (GND), J101.B12 (GND), J101.S1 (SHIELD), J102.A1 (GND), J102.A12 (GND), J102.B1 (GND), J102.B12 (GND), J102.S1 (SHIELD), Q501.2 (S), R103.2, R104.2, R106.2, R107.2, R206.2, R209.2, R301.2, R304.2, R502.2, SW301.3 (K), SW301.4 (A), SW301.5, SW301.6, SW501.A, SW501.B, U202.2 (GND), U202.5 (WP), U203.28 (TEST), U203.30 (SD_WP), U203.37 (EPAD), U302.2 (GND), U302.5 (WP), U303.28 (TEST), U303.30 (SD_WP), U303.37 (EPAD), U401.1 (GND), U502.4 (GND), U505.3 (GND), U601.8 (GND), U601.15 (~EN), U602.8 (GND), U602.15 (~EN), U603.8 (GND), U603.15 (~EN), U604.A6 (VSS), U604.C4 (VSSQ), U604.E7 (VSS), U604.G5 (VSS), U604.H10 (VSS), U604.J5 (VSS), U604.K8 (VSS), U604.N2 (VSSQ), U604.N5 (VSSQ), U604.P4 (VSSQ), U604.P6 (VSSQ), X101.2 (GND)
unnamed: C501.1, R509.1, U505.2
unnamed: D203.1 (K), R209.1
unnamed: D301.1 (K), R304.1
unnamed: D302.2 (A), R309.2
unnamed: D401.2 (A), FB301.2
unnamed: D402.2 (A), FB401.2
unnamed: D501.2 (A), R507.2
unnamed: D502.2 (A), R505.2
unnamed: D503.2 (A), R508.2
unnamed: J101.A5 (CC1), R104.1
unnamed: J101.B5 (CC2), R103.1
unnamed: J102.A5 (CC1), R107.1
unnamed: J102.B5 (CC2), R106.1
unnamed: Q501.3 (D), R506.1
unnamed: C502.1, Q501.1 (G), R501.2, R502.1
unnamed: C504.2, Q502.4 (G), R503.2, R506.2
unnamed: R504.2, R509.2, SW501.C, SW501.D
unnamed: R206.1, U203.35 (RBIAS)
unnamed: C205.1, U203.13 (VDD18)
unnamed: C204.1, U203.34 (VDD18PLL)
unnamed: R301.1, U303.35 (RBIAS)
unnamed: C305.1, U303.13 (VDD18)
unnamed: C303.1, U303.34 (VDD18PLL)
unnamed: U502.1 (C), U505.4
unnamed: C604.1, U604.C2 (VDDI)
unnamed: C606.1, R602.2, U604.K5 (~RST)
